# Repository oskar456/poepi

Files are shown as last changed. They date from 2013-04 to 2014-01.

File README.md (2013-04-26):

PoEpi: a multi purpose shield for Raspberry Pi
==============================================

This is a peripheral board for [Raspberry Pi](http://www.raspberrypi.org) with
three separate functions:

* Power supply with 12-40&nbsp;Volt input and 5&nbsp;Volt, 0.75&nbsp;Amps output,
with short circuit protection and simple passive PoE extractor (utilizes unused
pairs in a Fast Ethernet UTP cable).
* [1-Wire](http://en.wikipedia.org/wiki/1-Wire) controller
[DS2482-100](http://www.maximintegrated.com/datasheet/index.mvp/id/4382)
connected to I2C bus of Raspberry Pi.
* Real time clock module
[PCF8583](http://www.nxp.com/products/interface_and_connectivity/i2c/rtcs_with_i2c_interface/series/PCF8583.html)
with backup battery.

All schematics and board layouts are created using [EAGLE 6.2.1 beta](http://www.cadsoftusa.com).

For more informations, please visit [PoEpi pages](http://oskar456.github.io/poepi/).

List of schematics and boards
-----------------------------

* **PoEpi_v2**: current board design
* **PoEpi_proto**: old prototype board design
* **PoE_injector**: simple injector, utilizing unused pairs in a Fast Ethernet UTP cable.

### Copyright

Copyright 2013 Ondřej Caletka  
This work is licensed under a [Creative Commons Attribution 3.0 Unported License][lic].  
[][lic]

[lic]: http://creativecommons.org/licenses/by/3.0/
[licimg]: http://i.creativecommons.org/l/by/3.0/88x31.png

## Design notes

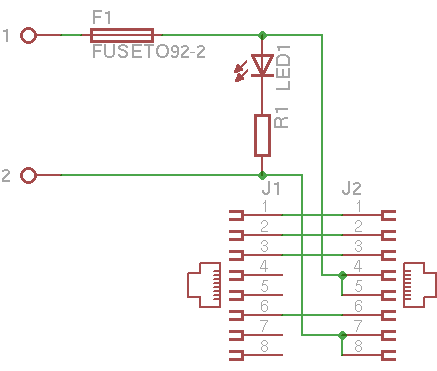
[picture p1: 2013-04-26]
PoE_injector/poe_injector.png

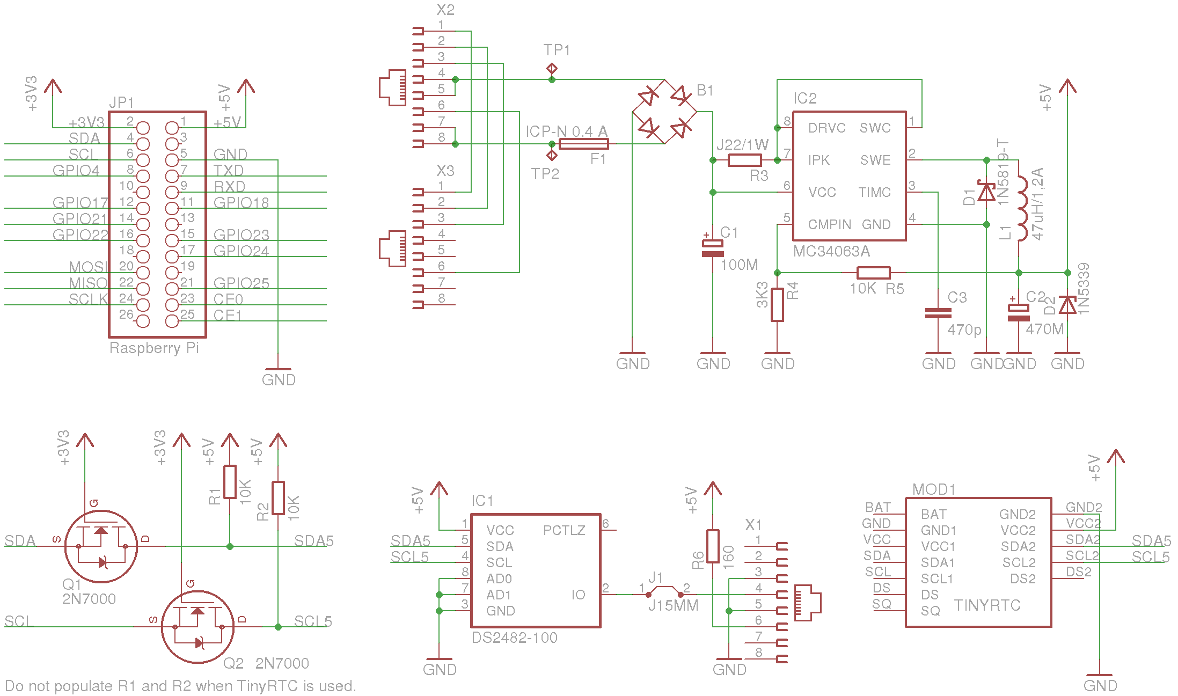
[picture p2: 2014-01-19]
PoEpi_v3/PoEpi_v3_300dpi.png

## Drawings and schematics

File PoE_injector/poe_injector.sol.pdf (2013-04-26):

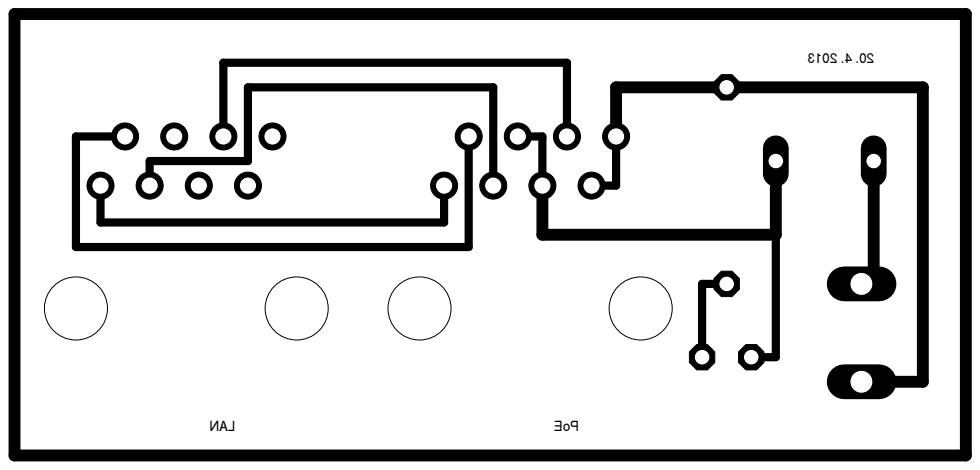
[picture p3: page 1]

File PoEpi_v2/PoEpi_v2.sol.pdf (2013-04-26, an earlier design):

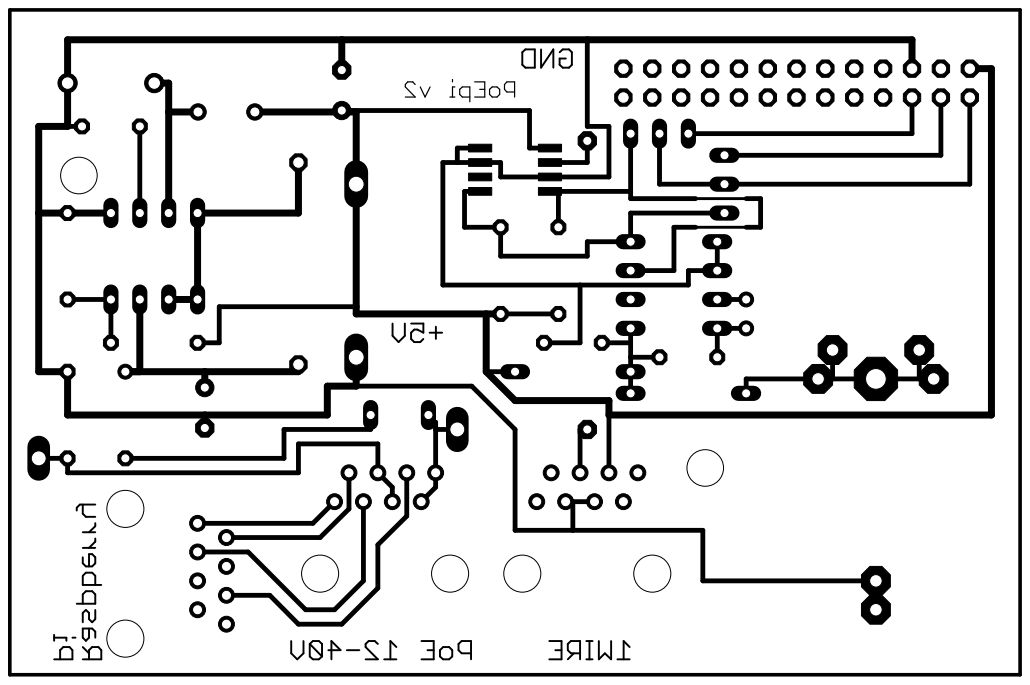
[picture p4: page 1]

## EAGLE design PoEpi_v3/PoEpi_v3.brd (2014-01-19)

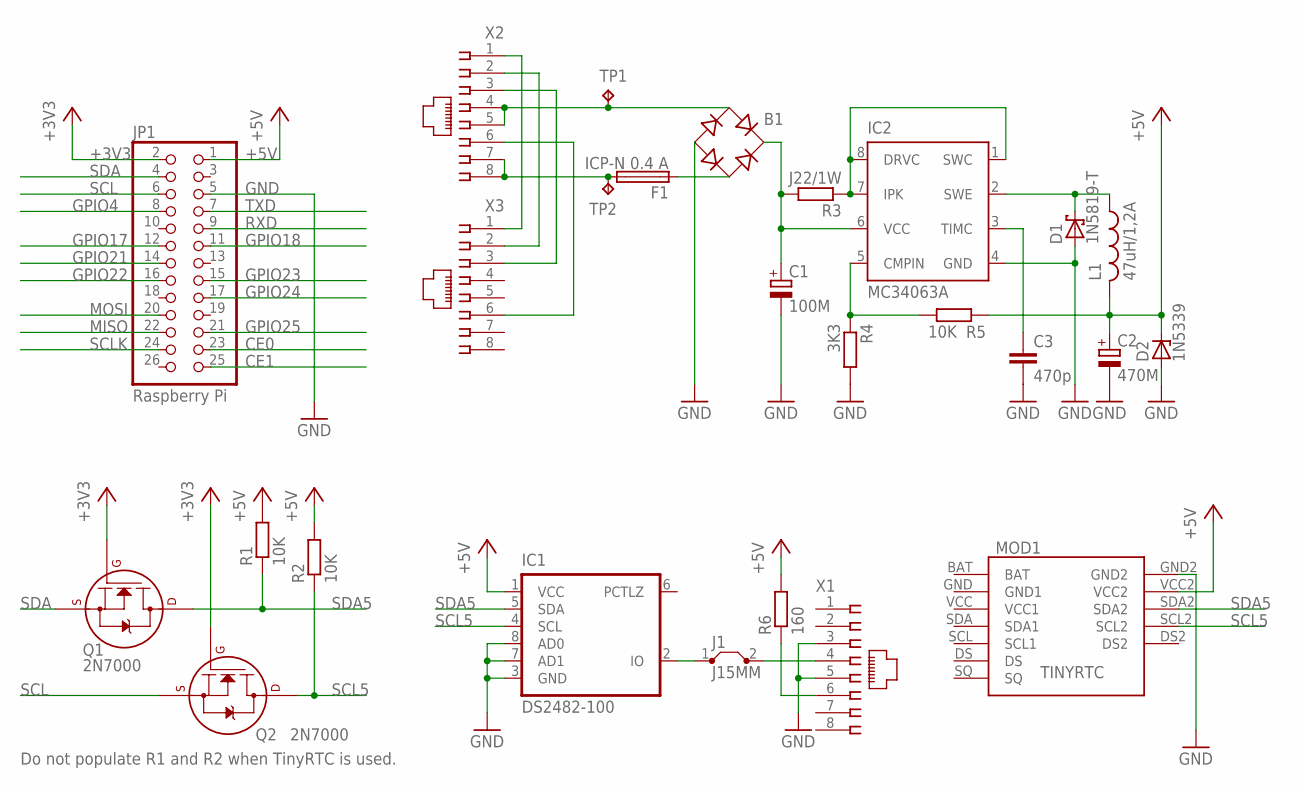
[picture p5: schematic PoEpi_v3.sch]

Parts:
B1: B-DIL
C1: 100M; E3,5-8
C2: 470M; E3,5-8
C3: 470p; C050-024X044
D1: 1N5819-T; DO41-7.6
D2: 1N5339; C1702-15
F1: ICP-N 0.4 A; TO92-2
IC1: DS2482-100; SO08
IC2: MC34063A; DIL8
J1: J15MM; 15
JP1: Raspberry Pi; 2X13
L1: 47uH/1,2A; 6000-XXXX-RC
MOD1: TINYRTC; TINYRTCMODULE
Q1, Q2: 2N7000; TO92-
R1, R2, R5: 10K; 0204/7
R3: J22/1W; 0617/17
R4: 3K3; 0204/7
R6: 160; 0204/7
TP1, TP2: TPPAD1-13Y; P1-13Y
X1, X2, X3: 520251-4

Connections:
+3V3: JP1.2 (1), Q1.2 (G), Q2.2 (G)
+5V: C2.+, D2.C, IC1.1 (VCC), JP1.1 (2), L1.2, MOD1.VCC2, R1.2, R2.2, R5.2, R6.2
BAT: MOD1.BAT
CE0: JP1.23 (24)
CE1: JP1.25 (26)
GND: B1.-, C1.-, C2.-, C3.2, D1.A, D2.A, IC1.3 (GND), IC1.7 (AD1), IC1.8 (AD0), IC2.4 (GND), JP1.5 (6), MOD1.GND2, R4.2, X1.3, X1.5
GND1: MOD1.GND (GND1)
GPIO4: JP1.8 (7)
GPIO17: JP1.12 (11)
GPIO18: JP1.11 (12)
GPIO21: JP1.14 (13)
GPIO22: JP1.16 (15)
GPIO23: JP1.15 (16)
GPIO24: JP1.17 (18)
GPIO25: JP1.21 (22)
MISO: JP1.22 (21)
MOSI: JP1.20 (19)
unnamed: X2.1, X3.1
unnamed: X2.2, X3.2
unnamed: X2.3, X3.3
unnamed: X2.6, X3.6
unnamed: F1.3 (2), TP2.TP, X2.7, X2.8
unnamed: B1.AC1, TP1.TP, X2.4, X2.5
unnamed: IC2.1 (SWC), IC2.7 (IPK), IC2.8 (DRVC), R3.1
unnamed: IC2.5 (CMPIN), R4.1, R5.1
unnamed: B1.+, C1.+, IC2.6 (VCC), R3.2
unnamed: C3.1, IC2.3 (TIMC)
unnamed: R6.1, X1.6
unnamed: D1.C, IC2.2 (SWE), L1.1
unnamed: B1.AC2, F1.1
ONEWIRE: IC1.2 (IO), J1.1
ONEWIRE2: J1.2, X1.4
RXD: JP1.9 (10)
SCL: JP1.6 (5), Q2.3 (S)
SCL5: IC1.4 (SCL), MOD1.SCL2, Q2.1 (D), R2.1
SCLK: JP1.24 (23)
SDA: JP1.4 (3), Q1.3 (S)
SDA5: IC1.5 (SDA), MOD1.SDA2, Q1.1 (D), R1.1
TXD: JP1.7 (8)
VCC1: MOD1.VCC (VCC1)

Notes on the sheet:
Do not populate R1 and R2 when TinyRTC is used.

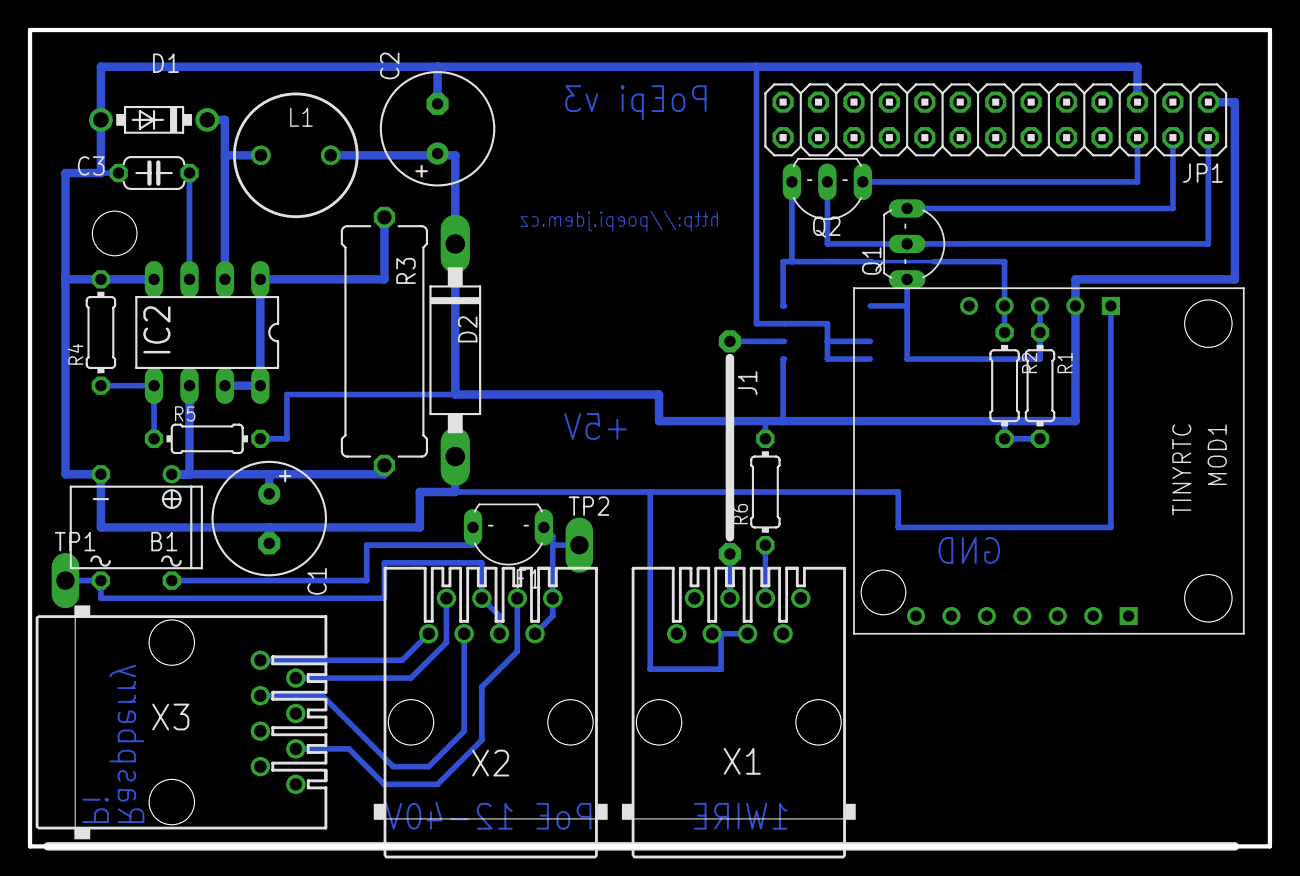
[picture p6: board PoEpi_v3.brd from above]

Board: 2 copper layers, 88.9 x 58.5 mm, 26 parts (1 on the bottom side), 22 nets.

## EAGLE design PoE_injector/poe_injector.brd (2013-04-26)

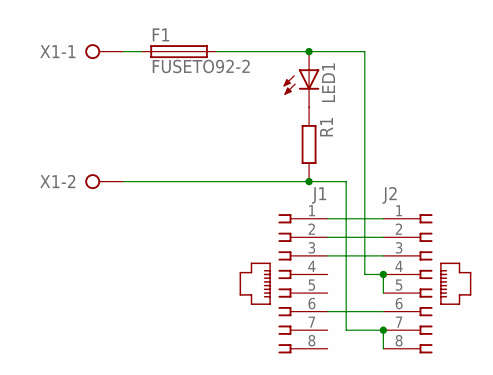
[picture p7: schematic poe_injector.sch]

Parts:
F1: FUSETO92-2; TO92-2
J1, J2: 520251-4
LED1: LED3MM
R1: R-EU_0207/10; 0207/10
X1: W237-02P; W237-132

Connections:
GND-7,8: J2.7, J2.8, R1.2, X1.2
unnamed: J1.1, J2.1
unnamed: J1.2, J2.2
unnamed: J1.3, J2.3
unnamed: J1.6, J2.6
unnamed: LED1.K (C), R1.1
unnamed: F1.1, X1.1
VCC-5,6: F1.3 (2), J2.4, J2.5, LED1.A

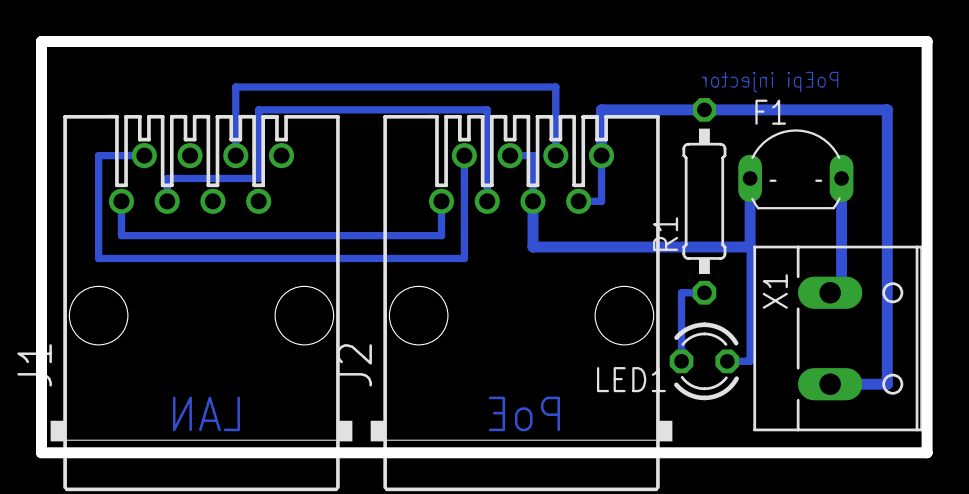
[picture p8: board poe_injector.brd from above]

Board: 2 copper layers, 49.2 x 22.9 mm, 6 parts (0 on the bottom side), 8 nets.

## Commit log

2013-04-26 Import project files
    [PoEpi_proto.brd, PoEpi_proto.sch, PoEpi_v2.brd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]
2013-04-26 Schematics cleanup
    [PoEpi_v2.brd, PoEpi_v2.sch]
2013-04-26 PoE injector cleanup, added png and PDF
    [poe_injector.brd, poe_injector.sch]
2014-01-19 Add version 3
    This version uses TinyRTC module for Arduino for RTC
    TinyRTC is much more cheaper than RTC from discrete components
    (http://jdem.cz/9jme9) but precission is not very good.
    [PoEpi_v3.brd, PoEpi_v3.sch]
